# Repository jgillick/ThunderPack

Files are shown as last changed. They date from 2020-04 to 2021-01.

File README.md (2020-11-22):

# ThunderPack

ThunderPack Board

A kick-ass microcontroller board with everything you need in a tiny package that fits in your pocket. Integrated battery & power management system, fast ARM microcontroller, USB bootloader, 4 high-power PWM outputs, 12 GPIOs, satisfying pushbutton switch, and more.

After years of wiring together portable LED controllers that all consisted of a lithium battery, charge controller, shitty slide power switch, and an Arduino nano (or similar), I wanted something better. I always found those versions to be janky and fragile -- not to mention concerned that damaging the pouch cell battery might make it explode in my pocket! This board has everything I need with room to expand.



* [Overview](https://github.com/jgillick/ThunderPack/wiki/)
* [Getting started](https://github.com/jgillick/ThunderPack/wiki/Getting-Started)
* [Pins & functions](https://github.com/jgillick/ThunderPack/wiki/Pinout-Details)
* [Example Programs](./examples)
* [Project log](https://hackaday.io/project/161054-lit-fist)

## Features

ThunderPack Board

* Fast 96Mhz 32-bit ARM microcontroller ([STM32F11xx](https://www.st.com/resource/en/datasheet/stm32f411ce.pdf))
* Integrated high power 500mA lithium battery charger
* 4 high-current PWM outputs (1.4 - 2.3A per channel!) with an LED on each for debugging.
* Additional 12 GPIOs (USART, I2C, SPI, USB)
* 16MB onboard flash
* RGB DotStar LED
* Built-in USB
* Tactile on/off switch
* Momentary button with built-in debounce circuit
* Breadboard friendly
* Supports Arduino & CircuitPython.

On the breadboard

## Board & Pinout

### v1.2 Compact
The newest & smallest Thunderpack, measuring in at a minuscule 4cm x 1.9cm (1.6 x 0.75 inches)! The PWM pins on this model can each drive 1.4A to ground (common cathode).

Compact pinout diagram

[See the full list of pins and details.](https://github.com/jgillick/ThunderPack/wiki/Pinout-Details)

### v1.2 Original
This is the original ThunderPack form factor and has the battery attached right to the circuit board. The PWM pins on this model can each drive 2.3A to ground (common cathode).

Original pinout diagram

[See the full list of pins and details.](https://github.com/jgillick/ThunderPack/wiki/Pinout-Details)

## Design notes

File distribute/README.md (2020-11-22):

# Distribution

This directory contains the default CircuitPython firmware and example code installed onto every ThunderPack that I ship.

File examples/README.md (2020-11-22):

# Example Programs

Thunder Pack can be programed with a variety of languages, libraries and frameworks; each at varying levels of abstraction. CircuitPython and Arduino, for example, have the highest level of abstraction and you don't need to understand much of the inner workings of the chip to get it to do some complex tasks. STM32Cube is at the opposite end of the spectrum where you're working much closer to the chip level. Often this layer of abstraction between the software and hardware is referred to as the Hardware Abstraction Layer (HAL). If you've never programmed microcontrollers before, CircuitPython or Arduino is a great place to start.

I've included a series of simple examples across the following libraries/environments to get you started:

* [CircuitPython](./CircuitPython) - Easily program the board with the Python language. By far the easiest way to start.
* [Arduino](./Arduino) - A common starting place for hobbyists, artists and those new to programming hardware.
* [ChibiOS](./ChibiOS) - A compact [real-time operating system](https://en.wikipedia.org/wiki/Real-time_operating_system) which includes threads & it's own hardware abstraction layer.
* [LibOpenCM3](./libopencm3) - An open source and comprehensive hardware abstraction layer in C and C++.
* [STM32Cube](./STM32Cube) - The default hardware abstraction layer provided by STMicroelectronics and contains quite a few lower level APIs.

Each directory has a README file which explains how to setup, compile and flash the software for that library.

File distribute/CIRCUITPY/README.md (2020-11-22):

ThunderPack 1.2
===============
https://github.com/jgillick/thunderpack/wiki

WARNINGS!
----------------
* ALWAYS use batteries with BUILT-IN protection circuits. _(ThunderPack board does not have any battery protection)_
* Do NOT plug the battery in backward or you could damage the board. (see instructions, below)
* Do NOT exceed the maximum rated power of the battery or components on the board.
* You CANNOT charge the battery through the VIN pin.
* ThunderPack should NOT be used as a chew toy.

ThunderPack was designed for fun and is not intended for life-supporting or business-critical applications.

Maximum Ratings
----------------
* Power Switch maximum ratings: 1A/30V (note 1)
* LED MOSFET maximum ratings:  2.3A/20V
* Onboard Voltage Regulator (AP2210N-3.3TRG1)
  * Output: 3.3V/300mA
  * Input (USB): 2.5-13.2V
* Onboard battery charger (BQ21040): 800mA/4.2V
* Power Pins:
  * 3.3v: 300mA
  * VUSB: USB host max current
  * BATT+: Battery max current
  * VIN: VUSB or BATT+ max (depending on which is powering the board)

Note 1:
You might be wondering how to use the 2.3A MOSFETs if the power switch is only rated at 1A. The MOSFETS are, themselves, switches, so you can connect an LED (or another device) directly from the BATT+ pin to any of the 4 LED pins. The main power switch will control the power to the MCU and that will control switching the MOSFETs. DO NOT connect a high current device directly to VIN, 3.3v, or VUSB.

Getting Started
----------------

### INSERTING THE BATTERY
Look at the diagram on the bottom of the board to see which direction to install the battery. Inserting it backward can damage the board.

The negative end of the battery should be on the USB-side, and the positive side should be on the power switch side of the board.

### RUNNING YOUR FIRST PROGRAM
ThunderPack comes loaded with CircuitPython and a simple test program. Turn the board on with the power switch and you should see the 4 LEDs light up in order. If you do not see this, the battery might be dead. Plug it into a USB charger and charge the battery.

When you plug the board into your computer it should mount as a CircuitPython drive device.
Flashing new firmware
If you want to continue using CircuitPython, updating the firmware is as simple as updating code.py on the USB drive which appears when you plug the board into your computer.

Otherwise, pressing the small tactile button next to the power button while you turn the board on will put it into programming mode. Now you can flash a new firmware program to the board.

### FLASHING FIRMWARE
On most systems, the dfu-util command-line tool (http://dfu-util.sourceforge.net/) will be the easiest way to get new firmware onto the board.

You can confirm that the board is in firmware programming mode by running:
dfu-util --list

To flash a new firmware program (firmware.bin) to the board, run a command like this:
dfu-util -d 0483:df11 -a 0 -s 0x08000000:leave -D ./firmware.bin

### EXAMPLES
There are many examples available for ThunderPack written with Arduino, ChibiOS, libopencm3, CircuitPython, and STM32Cube. You can browse the example library here:
https://github.com/jgillick/ThunderPack/tree/master/examples

Feel free to submit more examples to the project!

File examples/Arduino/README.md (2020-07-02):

# Arduino

Arduino is a great place to start if you're just getting started with microcontrollers. It uses a simplified programming structure with C or C++.

Arduino support is provided on the ThunderPack by the [STM32duino project](https://github.com/stm32duino/Arduino_Core_STM32).

## Software Prerequisites
* [Arduino](https://www.arduino.cc/en/Main/Software)
   * Then install [STM32 Cores 1.8+](https://github.com/stm32duino/wiki/wiki/Getting-Started) in your Arduino application.
* [STM32CubeProgrammer](https://www.st.com/en/development-tools/stm32cubeprog.html)

ℹ️ Mac users: There is a known issue with installing STM32CubeProgrammer on mac. You'll likely need to install it through your terminal application. [more info](https://community.st.com/s/question/0D50X00009XkWmr/install-stm32cubeprogrammer-on-mac-osx-fails-hangs-at-step-6-of-8)

## Setup

Open your Arduino application and make the following selections under the Tools menu:

* Board: Generic STM32L0 series
* Board part number: ThunderPack
* Upload method: STM32CubeProgrammer (DFU)



⚠️ If you do not see those options, make sure that you have [STM32 Cores 1.8+](https://github.com/stm32duino/wiki/wiki/Getting-Started) installed in your Arduino application.

## Programming

1. Open the `ino` file (i.e. Blink.ino) in your Arduino application.
2. Plug your ThunderPack into your computer with a USB cable.
3. Put the ThunderPack in bootloader mode by pressing the tactile button *while* you turn it on. (i.e. press both buttons at the same time)
4. Click Sketch > Upload

Now the program will be compiled and automatically uploaded to your ThunderPack (this might take a couple minutes). If all goes well, and no errors occur, the example program should start automatically.

# Building & Programming

[Instructions](https://github.com/jgillick/ThunderPack/wiki/Getting-Started#arduino) on how to build an example and program it to your ThunderPack with Arduino.

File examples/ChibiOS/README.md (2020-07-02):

# ChibiOS Examples

These examples are written using the [ChibiOS RTOS](http://chibios.org/dokuwiki/doku.php).

## Prerequisites

### Software

* GCC build essentials.
  * Mac: Run `xcode-select --install` in your terminal.
  * Linux: Install [build-essential](https://packages.ubuntu.com/xenial/build-essential)
  * Windows: [make](http://gnuwin32.sourceforge.net/packages/make.htm) or via [cygwin](http://www.cygwin.com/)
* [The ARM gcc toolchain, 7.3.1 or above](https://developer.arm.com/tools-and-software/open-source-software/developer-tools/gnu-toolchain/gnu-rm)
* [dfu-util](http://dfu-util.sourceforge.net/)
* ChibiOS Supporting Files (see below)

### ChibiOS Library

The ChibiOS library is included as a git submodule and needs to be initialized before you can compile any of the examples. (These steps should only need to be run once)

```bash
git submodule init
git submodule update
```

## Compiling

1. Be sure you've installed the prerequisite software and initialized the ChibiOS library first. (see instructions above)
2. Now go into one of the example directories and run `make`.

## Flash the program

Put the board into bootloader (DFU) mode by pressing the user button while turning the board on. Now you can run the following command to flash the program to the board:

```bash
make flash
```

This command is a wrapper for the `dfu-util` command. The full command would be:

```bash
dfu-util -d 0483:df11 -a 0 -s 0x08000000:leave -D build/program.bin
```

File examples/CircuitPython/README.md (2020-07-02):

# CircuitPython / MicroPython
[CircuitPython](https://circuitpython.org/) enables Python code to run on the Thunderpack and is one of the easiest ways to get started with Microcontrollers. But first, you'll need to load the CircuitPython framework onto the board.

You can download the CircuitPython runtime binary for Thunderpack from here:
https://circuitpython.org/board/thunderpack/

Then use the following setup instructions to learn how to get this binary running on Thunderpack.

## Initial Setup
First make sure you have either [dfu-util](http://dfu-util.sourceforge.net/) or [STM32CubeProg](https://www.st.com/en/development-tools/stm32cubeprog.html) installed on your computer.

### Enter DFU bootloader mode
Put the ThunderPack in bootloader mode by pressing the tactile button *while* you turn it on. (i.e. press both buttons at the same time)

### Updating the board

#### DFU-UTIL
If you're using dfu-util, run this command (be sure the path to the `.bin` file is correct):

```bash
dfu-util -d 0483:df11 -a 0 -s 0x08000000:leave -D ./adafruit-circuitpython-thunderpack-en_US-5.2.0.bin
```

#### STM32CubeProg
If your're using STM32Cube, open the application and use it to program [the binary](https://circuitpython.org/board/thunderpack/) to the board.

You can see comprehensive instructions with screenshots [here](https://learn.adafruit.com/adafruit-stm32f405-feather-express/dfu-bootloader-details).

## Using CircuitPython
If everything worked right, when you restart your board it will mount to your computer as a disk drive called "CIRCUITPY". This can take up to 30 seconds on the first boot.

To try an example, simply add the `code.py`file (and the `lib` directoy, if present) to the mounted drive and in few seconds the board will update to run it.

Learn more at [CircuitPython](https://circuitpython.org/)

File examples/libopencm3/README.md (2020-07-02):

# LibOpenCM3

Examples written using the [libopencm3](https://github.com/libopencm3/libopencm3) library.

## Prerequisites

### Software

* GCC build essentials.
  * Mac: Run `xcode-select --install` in your terminal.
  * Linux: Install [build-essential](https://packages.ubuntu.com/xenial/build-essential)
  * Windows: [make](http://gnuwin32.sourceforge.net/packages/make.htm) or via [cygwin](http://www.cygwin.com/)
* [The ARM gcc toolchain, 7.3.1 or above](https://developer.arm.com/tools-and-software/open-source-software/developer-tools/gnu-toolchain/gnu-rm)
* [dfu-util](http://dfu-util.sourceforge.net/)

### LibOpenCM3 Library

The LibOpenCM3 library is included as a git submodule and needs to be initialized and built before you can compile any of the examples. (These steps should only need to be run once)

```bash
cd ThunderPack/examples/libopencm3
git submodule init
git submodule update
make
```

## Compile

1. Be sure you've installed the prerequisite software and initialized the LibOpenCM3 library first. (see instructions above)
2. Now go into one of the example directories and run `make`.

**For Example:**

```bash
cd examples/libopencm3

make

cd ./Blink

make
```

## Flash the program

Put the board into bootloader (DFU) mode by pressing the user button while turning the board on. Now you can run the following command to flash the program to the board:

```bash
make flash
```

This command is a wrapper for the `dfu-util` command. The full command would be:

```bash
dfu-util -d 0483:df11 -a 0 -s 0x08000000:leave -D build/program.bin
```

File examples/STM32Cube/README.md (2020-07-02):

# STM32Cube

Examples written using [STM32Cube](https://www.st.com/content/st_com/en/products/embedded-software/mcu-mpu-embedded-software/stm32-embedded-software/stm32cube-mcu-mpu-packages/stm32cubef4.html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), which are the official hardware extraction layer (HAL) and libraries from STMicroelectronics.

The base configurations (clock, gpio, etc) are generated using the [STM32CubeMX](https://www.st.com/en/development-tools/stm32cubemx.html) code generator.

## Prerequisites

### Software

* GCC build essentials.
  * Mac: Run `xcode-select --install` in your terminal.
  * Linux: Install [build-essential](https://packages.ubuntu.com/xenial/build-essential)
  * Windows: [make](http://gnuwin32.sourceforge.net/packages/make.htm) or via [cygwin](http://www.cygwin.com/)
* [The ARM gcc toolchain, 7.3.1 or above](https://developer.arm.com/tools-and-software/open-source-software/developer-tools/gnu-toolchain/gnu-rm)
* [dfu-util](http://dfu-util.sourceforge.net/)

## Compile

To compile each example, you should only need to run `make` from within the example directory.

```bash
cd ./Blink

make
```

## Flash the program

Put the board into bootloader (DFU) mode by pressing the user button while turning the board on. Now you can run the following command to flash the program to the board:

```bash
make flash
```

This command is a wrapper for the `dfu-util` command. The full command would be:

```bash
dfu-util -d 0483:df11 -a 0 -s 0x08000000:leave -D build/program.bin
```

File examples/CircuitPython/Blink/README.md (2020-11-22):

# Blink

The ubiquitous "Hello World" of hardware examples. This simply blinks the LED 1 (PA0). Pressing the button will blink the LED faster.

## Compiling/Flashing
See the instructions [here](../README.md)

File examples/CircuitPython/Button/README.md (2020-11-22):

# Button Example

Turns on LED 1 when the button is pressed.

## Compiling/Flashing
See the instructions [here](../README.md)

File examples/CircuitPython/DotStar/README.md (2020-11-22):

# DotStar
This CircuitPython example controls the onboard RGB dotstar LED and cycles it's color around the color wheel. You can easily modify this program to control external DotStar LEDs by changing the pins that are use.

## Compiling/Flashing
See the instructions [here](../README.md)

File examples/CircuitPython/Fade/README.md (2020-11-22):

# Fade

Uses PWM to fade LED 1 on and off.

## Compiling/Flashing
See the instructions [here](../README.md)

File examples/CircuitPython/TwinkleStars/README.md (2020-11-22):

# CircuitPython Twinkle Stars

This is a CircuitPython program which uses a few outputs and some fairy string lights to produce a cool twinkling stars effect. Some LEDs are set to twinkle on and off, while others will have a longer fade up and down.

Twinkling

## How Fairy String LEDs Help

Often fairy string lights wire up their LEDs parallel with alternating polarities. This way, when wire 1 is positive and wire 2 is negative, every second LED is illuminated. When the polarity of the wires reverses (wire 1: negative, wire 2: positive) the other LEDs turn on.

This clever technique let's fairy string lights do a variety of animations with fewer wires by swapping the polarities at different rates.

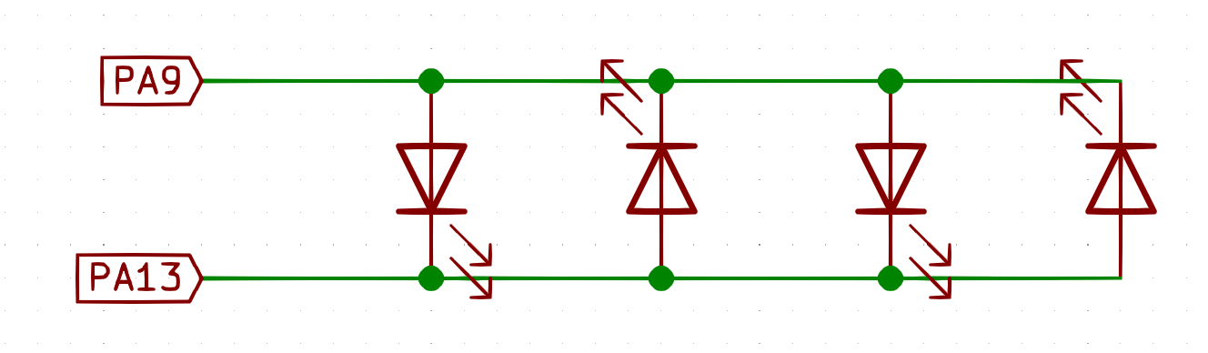
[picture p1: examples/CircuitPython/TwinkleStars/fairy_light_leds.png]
Fairy String LEDs Schematic


## Setup

There will be two groups of LEDs: twinkling and fading. The fading LEDs will just fade on and off. The twinkling LEDs will swap the power polarity to a string of LEDs with randomized timing.

### Fade LEDs

Connect LEDs to the first three PWM outputs, ensuring you have the polarity correct. The fading LEDS will not use the swapped polarity feature.

### Twinkle LEDs

Cut a string of fairy lights into sections. Test the current draw on each twinkle section and make sure it does not draw more than 20mA. If it does, you might need to add a mosfet to protect the microcontroller. Add an inline resistor as necessary.

Take each section and connect one of the wires to one GPIO and the other one to another GPIO. I used: `PA9`, `PA13`, `PA14`, and `PB5`.

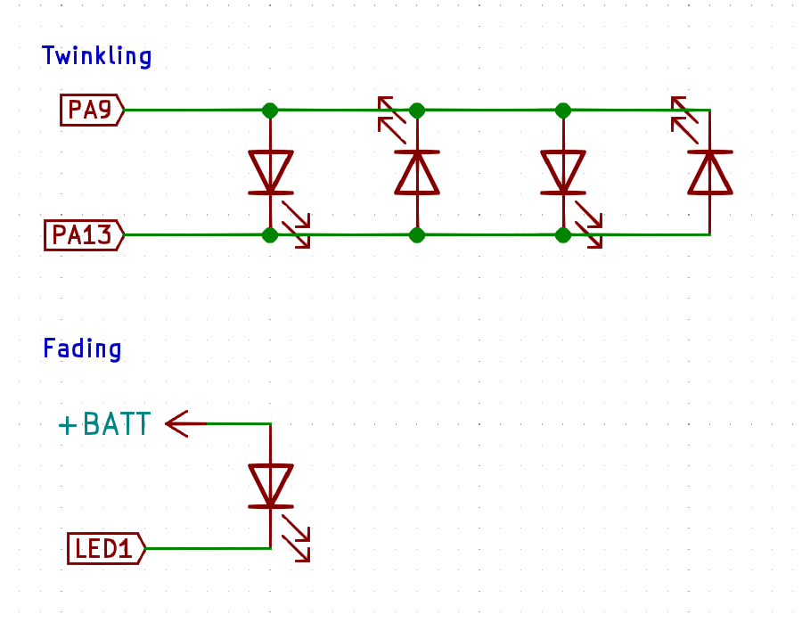
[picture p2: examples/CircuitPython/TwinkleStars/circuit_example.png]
Example Circuit


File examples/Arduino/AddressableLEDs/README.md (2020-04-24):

# Addressable LEDs (WS2812B)
Controls a string of addressable WS2812B LEDs (like [Neopixels](https://www.adafruit.com/category/168)). This example controls 16 LEDs, which is configurable by the `LED_COUNT` value in `src/main.c`.

## Connections

From the LED strip, connect:

* Data -> `PA7`
* Power -> `Vin` or `Batt+`
* Ground -> `GND`

## WS2812B API Library
Read about how to use the provided WS2812B APIs in the [WS2812b.h](./WS2812b.h) file.

### Example
```cpp
// Initialize LED strip
#define DATA_PIN  PA7
#define LED_COUNT 16
WS2812b led_strip = WS2812b(DATA_PIN, LED_COUNT);

// Set brightness on 3 neopixels
led_strip.set(0, 0xFF, 0x00, 0x00); // LED 1 red
led_strip.set(1, 0x00, 0xFF, 0x00); // LED 2 green
led_strip.set(2, 0x00, 0x00, 0xFF); // LED 3 blue

// Send data (if you forget this line, nothing will be sent to your LED strip)
led_strip.show();
```

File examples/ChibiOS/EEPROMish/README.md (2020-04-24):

# EEPROMish - Non-Volatile Memory

A simple example to demonstrate storing a value in non-volatile memory.

When the program starts, one of the LEDs will light up. Pressing the button will light the next LED, and so on and so forth. When you turn the board off and on again, the previously lit LED will be remembered and be the starting LED.

## STM32Cube with Chibios

ChibiOS doesn't have any functions to interface with on-board flash memory for the STM32F411 chip, so this example shows how to include the [STM32Cube library](https://www.st.com/content/st_com/en/products/embedded-software/mcu-mpu-embedded-software/stm32-embedded-software/stm32cube-mcu-mpu-packages/stm32cubel0.html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) into a ChibiOS project and use the flash functions in it.

In this case we're using the driver files located in the [STM32Cube examples](../../STM32Cube/) directory. You can just as easily use files generated by the STM32CubeMX tool.

## How it works
The STM32F411 chip does not have built-in [EEPROM memory](https://en.wikipedia.org/wiki/EEPROM). However, it allows you to write to sectors of it's internal flash memory in a similar way to EEPROM.

Each time the user presses the button to change the lit LED, the code saves this value to a byte address in the flash memory.

Inside the chip, the flash memory is devided into 11 sectors. In our case we reserved sector 1 for non-volatile memory. Before writing to a sector, the entire sector needs to be erased. To prevent the firmware from being loaded into this section, we updated the linker file ([STM32F411CEUx_FLASH_NVM.ld](./STM32F411CEUx_FLASH_NVM.ld)) to reserve sector 1 for data.

### What's the catch?
There are a few:

* It uses the same memory as the firmware, so it _might_ be erased when the firmware is updated.
* Writing to flash is slower than EEPROM.
* Flash memory might start corrupting after 10k write cycls. EEPROM can handle up to 1 million write cycles.

### Additional information
This example is pretty basic, but if you plan to write to this often, you might want to read about proper [EEPROM emulation techniques](https://www.st.com/resource/en/application_note/dm00036065-eeprom-emulation-in-stm32f40xstm32f41x-microcontrollers-stmicroelectronics.pdf).

## Compiling/Flashing
See the instructions [here](../README.md)

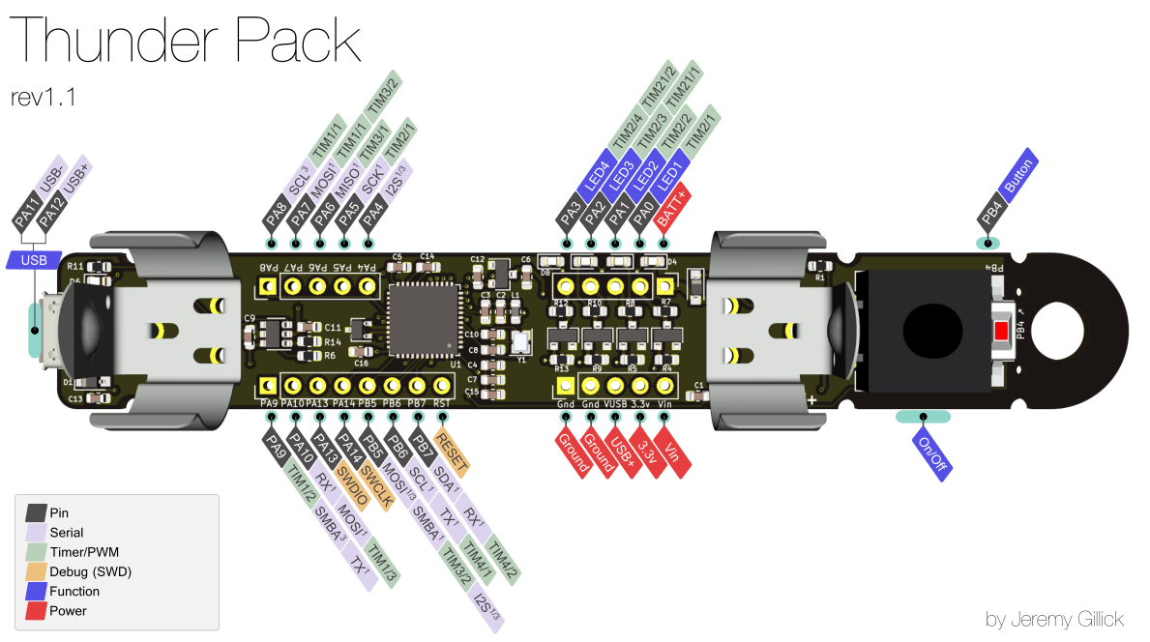
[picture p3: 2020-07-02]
images/pinout.png

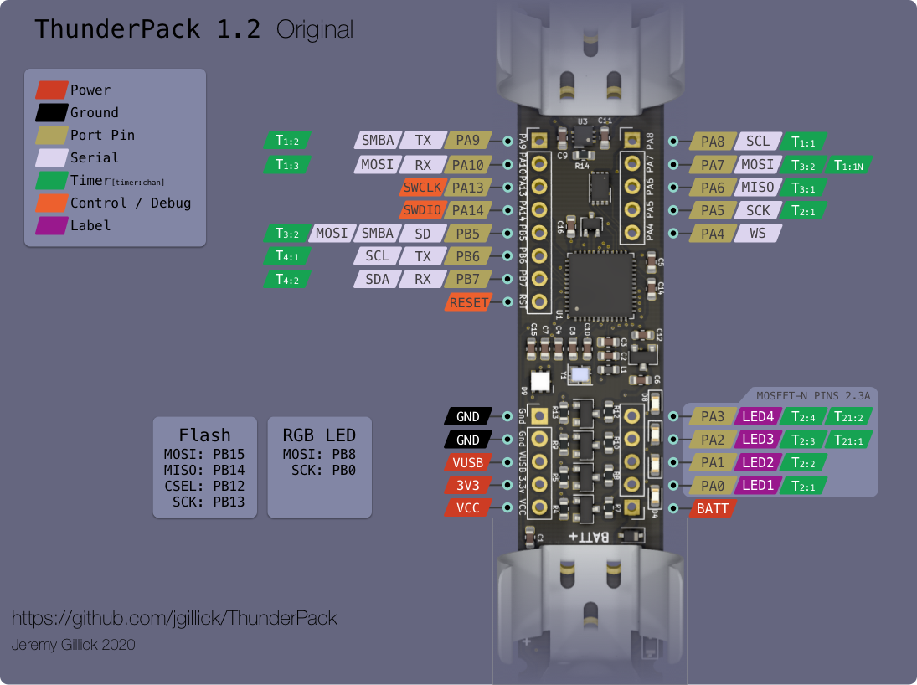
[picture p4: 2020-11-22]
hardware/Original/pinout/pinout_small.png

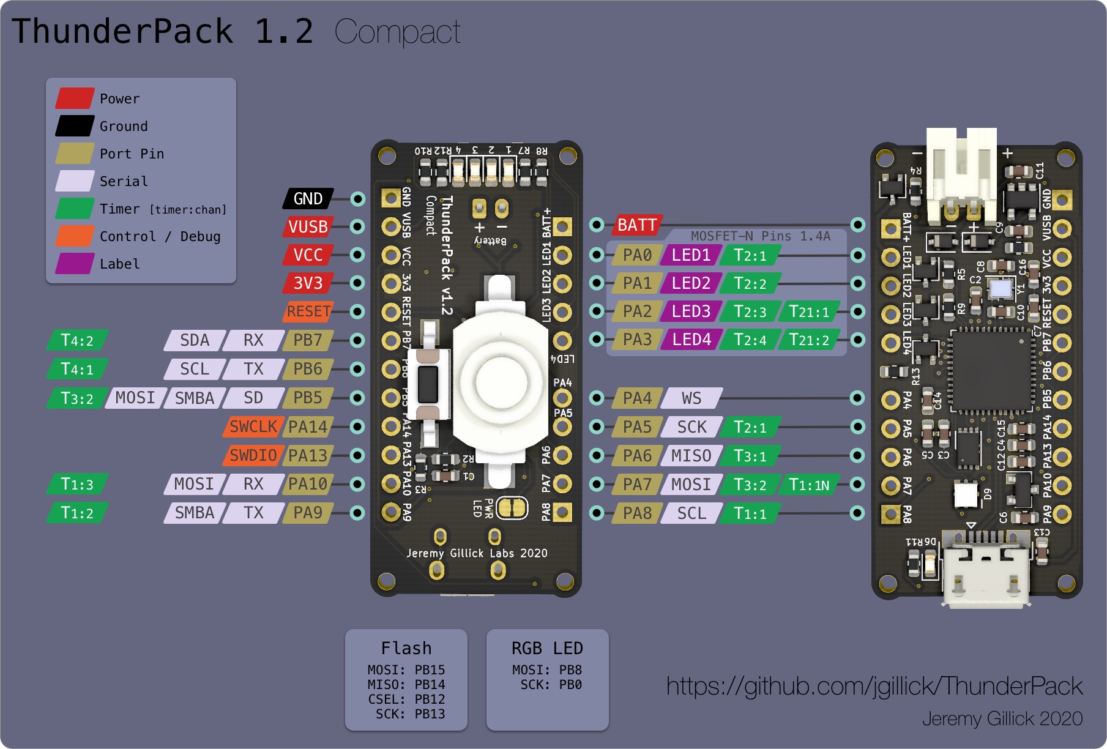
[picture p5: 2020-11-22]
hardware/Compact/pinout/pinout.jpg

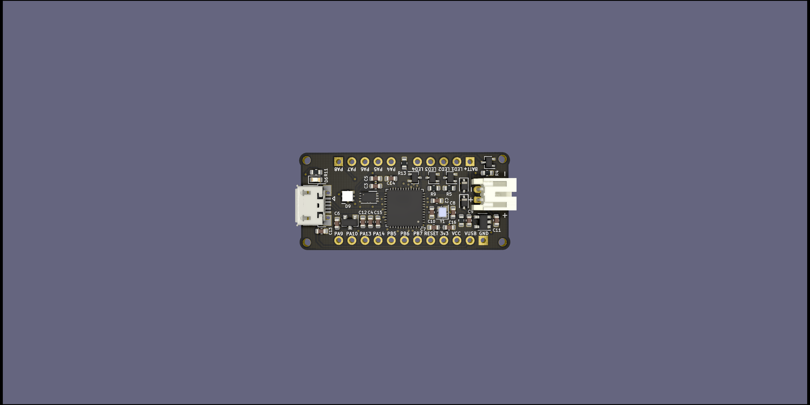
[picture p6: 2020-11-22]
hardware/Compact/Renderings/Back.png

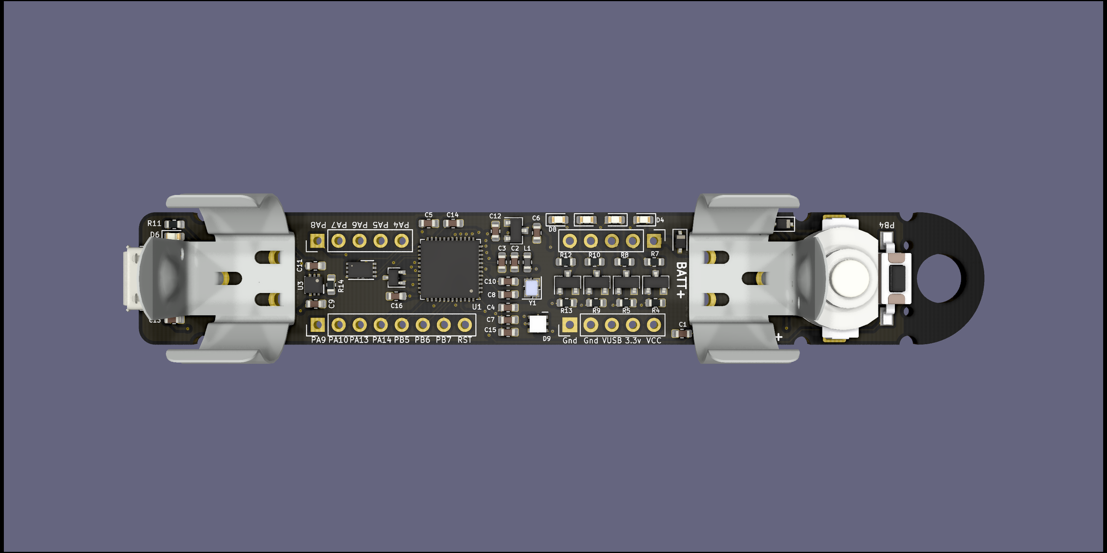
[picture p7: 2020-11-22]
hardware/Original/render.png

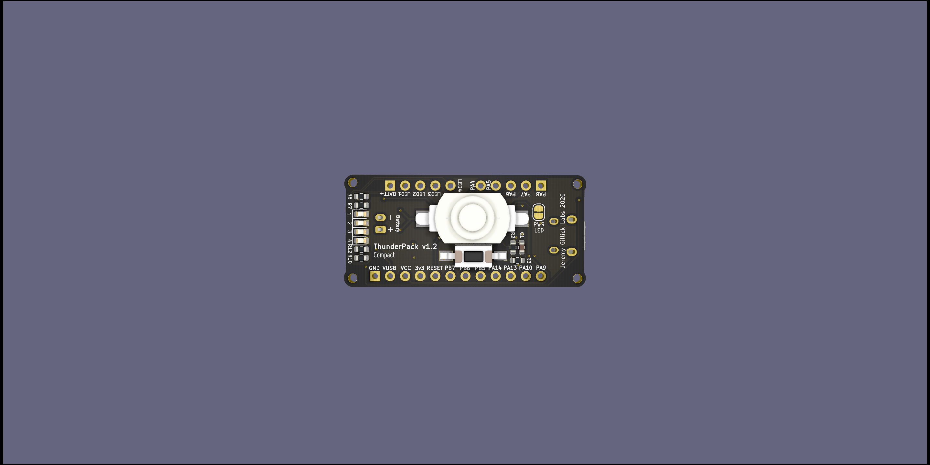
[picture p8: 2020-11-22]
hardware/Compact/Renderings/Front.png

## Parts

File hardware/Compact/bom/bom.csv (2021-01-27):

Id | Designator | Manufacturer | Quantity | *Mfg Part # | Value | Package | Description / Value | Type | Notes
1 | U4 | ON Semiconductor | 1 | ESD7002WTT1G |  | SOT-323_SC-70 | TVS DIODE 5V SC70-3 | SMD
2 | D9 | SparkFun Electronics | 1 | APA102-2020 |  | LED-APA102-2020 | ADDRESS LED STRIP SER RGB 10PK | SMD
3 | J2 | TE Connectivity | 1 | 440055-2 |  | JST_PH_S2B-PH-K_1x02_P2.00mm_Horizontal | Connector Header Through Hole, Right Angle 2 position 0.079" (2.00mm) | thru-hole
4 | R12,R10,R8,R7,R3,R11,R1 |  | 7 |  | 330 | 0603 | RES SMD 330 OHM 0.5% 1/5W 0603 | SMD
5 | D6 | Würth Elektronik | 1 | 150060SS75000 |  | 0603 | LED RED CLEAR 0603 SMD | SMD
6 | D8,D7,D5,D4 | Würth Elektronik | 4 | 150060VS75000 |  | 0603 | LED GREEN CLEAR 0603 SMD | SMD
7 | D1,D2 | Micro Commercial Co | 2 | SMD22WS-TP |  | SOD-323 | 2A,20V,SCHOTTKY,SOD-323 PACKAGE | SMD
8 | SW1 | TE Connectivity | 1 | FSMSM |  |  | SWITCH TACTILE SPST-NO 0.05A 24V | SMD
9 | U5 | GigaDevice Semiconductor | 1 | GD25Q16CEIGR |  | 8-XFDFN | FLASH - NOR Memory IC 16Mb (2M x 8) SPI - Quad I/O 120MHz 8-USON (2x3) | SMD
10 | U1 | STMicroelectronics | 1 | STM32F411CEU6 |  | 48-UFQFN | IC MCU 32BIT 512KB FLSH 48UFQFPN | SMD
11 | Q2,Q4,Q3,Q1 | Infineon Technologies | 4 | BSS816NWH6327XTSA1 |  | SOT-323 | MOSFET N-CH 20V 1.4A SOT323-3 | SMD
12 | R13,R9,R5,R4,R2 |  | 5 |  | 20k | 0603 | RES SMD 20K OHM 0.5% 1/10W 0603 | SMD
13 | C1,C4,C16,C5,C3 |  | 5 |  | 100nF | 0603 | CAP CER 0.1UF 50V X7R 0603 | SMD
14 | U3 | Microchip Technology | 1 | MCP73831T-2ACI/OT |  | SOT-23-5 | IC BATT CNTL LI-ION 1CEL SOT23-5 | SMD
15 | R6 |  | 1 |  | 2k | 0603 | RES 2K OHM 1% 1/10W 0603 | SMD
16 | C11,C9,C14,C7 |  | 4 |  | 4.7uF | 0603 | CAP CER 4.7UF 16V X5R 0603 | SMD
17 | D3 | Würth Elektronik | 1 | 150060BS55040 |  | 0603 | LED BLUE DIFFUSED 0603 SMD | SMD
18 | C12 |  | 1 |  | 2.2uF | 0603 | CAP CER 2.2UF 16V X5R 0603 | SMD
19 | Y1 | XRCGB24M000F0L00R0 | 1 | 24Mhz |  | 4-SMD | CRYSTAL 24.0000MHZ 6PF SMD | SMD
20 | U2 | Diodes Incorporated | 1 | AP2210N-3.3TRG1 |  | SOT-23-3 | IC REG LINEAR 3.3V 300MA SOT23-3 | SMD
21 | J4 | Amphenol ICC (FCI) | 1 | 10103594-0001LF |  |  | CONN RCPT USB2.0 MICRO B SMD R/A | SMD
22 | C13,C6,C2 |  | 3 |  | 1uF | 0603 | CAP CER 1UF 25V X5R 0603 | SMD
23 | C10,C8 |  | 2 |  | 6pF | 0603 | CAP CER 6PF 50V C0G/NP0 0603 | SMD

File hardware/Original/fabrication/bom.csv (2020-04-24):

Id | RefDefs | Package | Qty | Value | part number/description
1 | D2,D1 | D_SOD-323 | 2 | 20V2A | SMD22WS-TP
2 | Y1 | 4-SMD | 1 |  | XRCGB24M000F0L00R0
3 | U1 | 48-UFQFPN | 1 |  | STM32F411CEU6
4 | R6 | 603 | 1 | 680R
5 | C16,C15,C4,C1,C3,C5 | 603 | 6 | 100nF | CC0603KRX7R9BB104
6 | C14,C7 | 603 | 2 | 4.7uF | CC0603KRX5R5BB475
7 | U3 | SOT-23-6 | 1 |  | BQ21040
8 | D6 | 603 | 1 |  | 150060BS55040
9 | D8,D7,D5,D4 | 603 | 4 |  | 150060VS75000
10 | R14 | 603 | 1 | 10k
11 | R11,R3 | 603 | 2 | 330R
12 | C11,C12,C9,C13,C6,C2 | 603 | 6 | 1uF | CC0603KRX7R7BB105
13 | U4 | SOT-323_SC-70 | 1 |  | ESD7002WTT1G
14 | U2 | SOT-23 | 1 |  | AP2210N-3.3TRG1
15 | J4 | USB Micro | 1 |  | Amphenol 10103594-0001LF
16 | SW2 |  | 1 |  | GPTS203211B
17 | SW1 |  | 1 |  | TE Connectivity FSMSM
18 | L1 | 603 | 1 |  | BLM18TG601TN1D
19 | R1,R7,R8,R10,R12 | 603 | 5 | 270R
20 | R2,R4,R5,R9,R13 | 603 | 5 | 20k
21 | C8,C10 | 603 | 2 | 6pF | CL10C060CB8NNNC
22 | Q1,Q3,Q4,Q2 | SOT-23 | 4 |  | BSS806N
23 | D3 | 603 | 1 |  | 150060SS75000

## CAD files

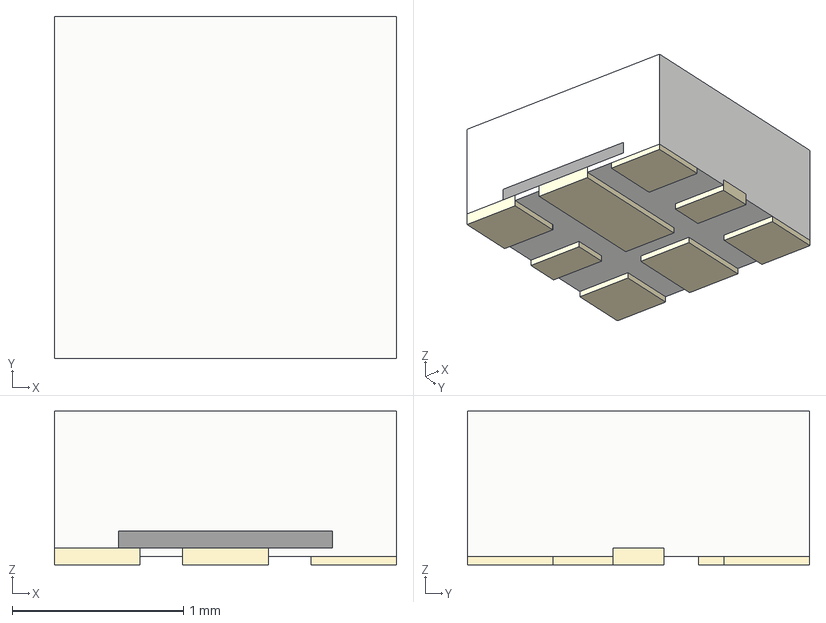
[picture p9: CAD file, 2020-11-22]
hardware/Compact/APA102-2020.step
2.00 x 2.00 x 0.9 mm
IC

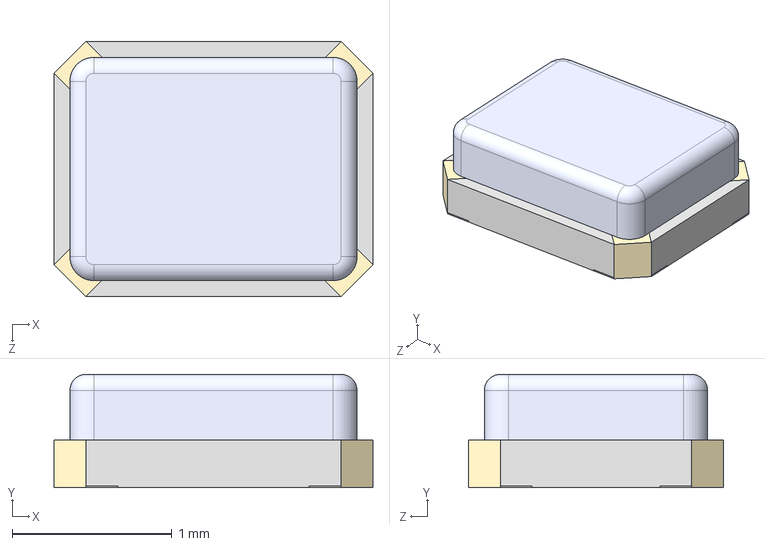
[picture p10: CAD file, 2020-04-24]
hardware/Original/XRCGB27M120F3A00R0--3DModel-STEP-56544.STEP
2.00 x 0.71 x 1.60 mm

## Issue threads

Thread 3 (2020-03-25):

Plans for selling these?

jamesmunns, 2020-03-25:
Hey there! This looks exactly like something I was planning to make (for a WS2812 dog collar), and I was wondering if you planned on selling these anywhere like Tindie.

For my use, either the STM32L0 or the new STM32F4 parts should work (I'll write the firmware in Rust instead of CircuitPython), so either revision works for me!

Thanks for sharing an awesome project!

jgillick, 2020-03-27:
Yeah, I was considering doing a small run and trying to sell a few on Tindie. I'm finishing up some of the remaining testing/documenting and then will put an order in and let you know.

If you plan to write some firmware in Rust, I'd love to get a boilerplate I could include in the examples sections. I've been planning to try learning Rust soon.

jamesmunns, 2020-03-27:
Sure! I recently did something similar for the [OtterPill](https://github.com/jamesmunns/OtterPill-rs/), the stm32 family is super well supported in Rust, so happy to contribute some boilerplate/examples.

I live in Germany, but happy to pay for international shipping as well, though it would be good to buy a couple boards at once :) probably count me in for 3-5, depending on the cost of each. I have a bunch of 18650s laying around, so i’d be interested in that version.

jgillick, 2020-03-28:
OtterPill is also a board I've been wanting to play with. Really nice design and I'm impressed with the cost the creator was able to get it down to.

Thanks for letting me know how many you're interested in. I'll let you know the price when I get the order setup with PCBWay.

mattpackwood, 2020-04-29:
Do you have a Tindie ID?

jgillick, 2020-05-02:
Not yet, but I'll be setting that up very soon. I should be getting the first batch of boards from the manufacturer sometime around middle of this month.

mattpackwood, 2020-05-02:
Hopefully, you can let me know when that happens!

mattytrentini, 2020-05-20:
Wouldn't mind getting my hands on one of these to create a MicroPython board definition. There are already existing [STM32F11 boards](https://github.com/micropython/micropython/tree/master/ports/stm32/boards) so it should be trivial...so yes, please let us know when you put sell these on Tindie!

jgillick, 2020-05-20:
PCBWay is running a little behind as they had a problem with sourcing one of the components. I'll let you know the updated timeline as soon as they get that to me.

@mattytrentini Yeah, creating a MicroPython board definition for this should be pretty straight forward!

jgillick, 2020-06-07:
Good news! I just received the small production run from PCBWay and they're beautiful. I'm still waiting on the shipment of batteries, but once I get them I'll be listing these for sale on my Tindie shop. (Shipping amid COVID is making things take much longer to receive than usual).

Tindie Shop: https://www.tindie.com/stores/jeremy/

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

jgillick, 2020-06-25:
It took MUCH longer to get this setup than expected, but I have the product listed on Tindie:
https://www.tindie.com/products/jeremy/thunderpack-18650/

Let me know if you need any help. This is my first time setting up a shop on Tindie.

Closed 2020-11-20.

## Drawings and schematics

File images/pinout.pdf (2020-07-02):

# Thunder Pack

# rev1.1

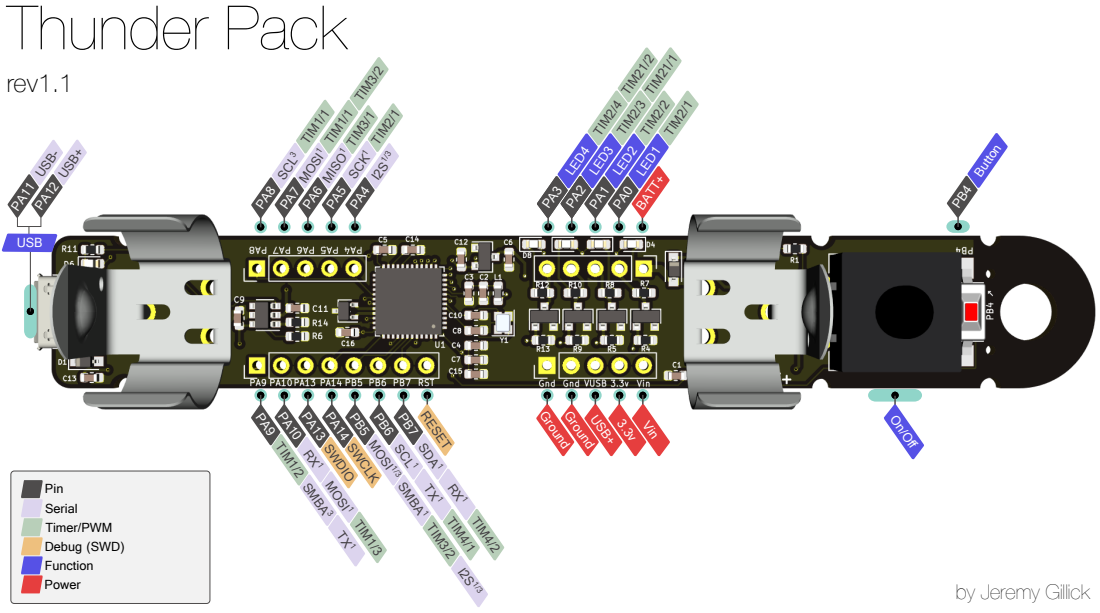
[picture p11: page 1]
MOSI1 TIM1/1; TIM3/2; TIM1/1; SCK1 TIM2/1; MISO1 PA6; TIM3/1; SCL3; TIM2/4; LED4; TIM21/2; TIM2/3; LED3; TIM21/1; TIM2/2; LED2; TIM2/1; LED1; BATT+; SMBA3; MOSI1; SWDIO; SWCLK; MOSI1/3; SMBA1 PB5; TIM1/2; TIM1/3; TIM4/1; TIM4/2; SCL1 TX1; SDA1 RX1; RESET; Ground USB+ 3.3v Vin; On/Off; Button; USB; USB-; USB+; Ground; Pin Serial Timer/PWM Debug (SWD) Function Power

by Jeremy Gillick

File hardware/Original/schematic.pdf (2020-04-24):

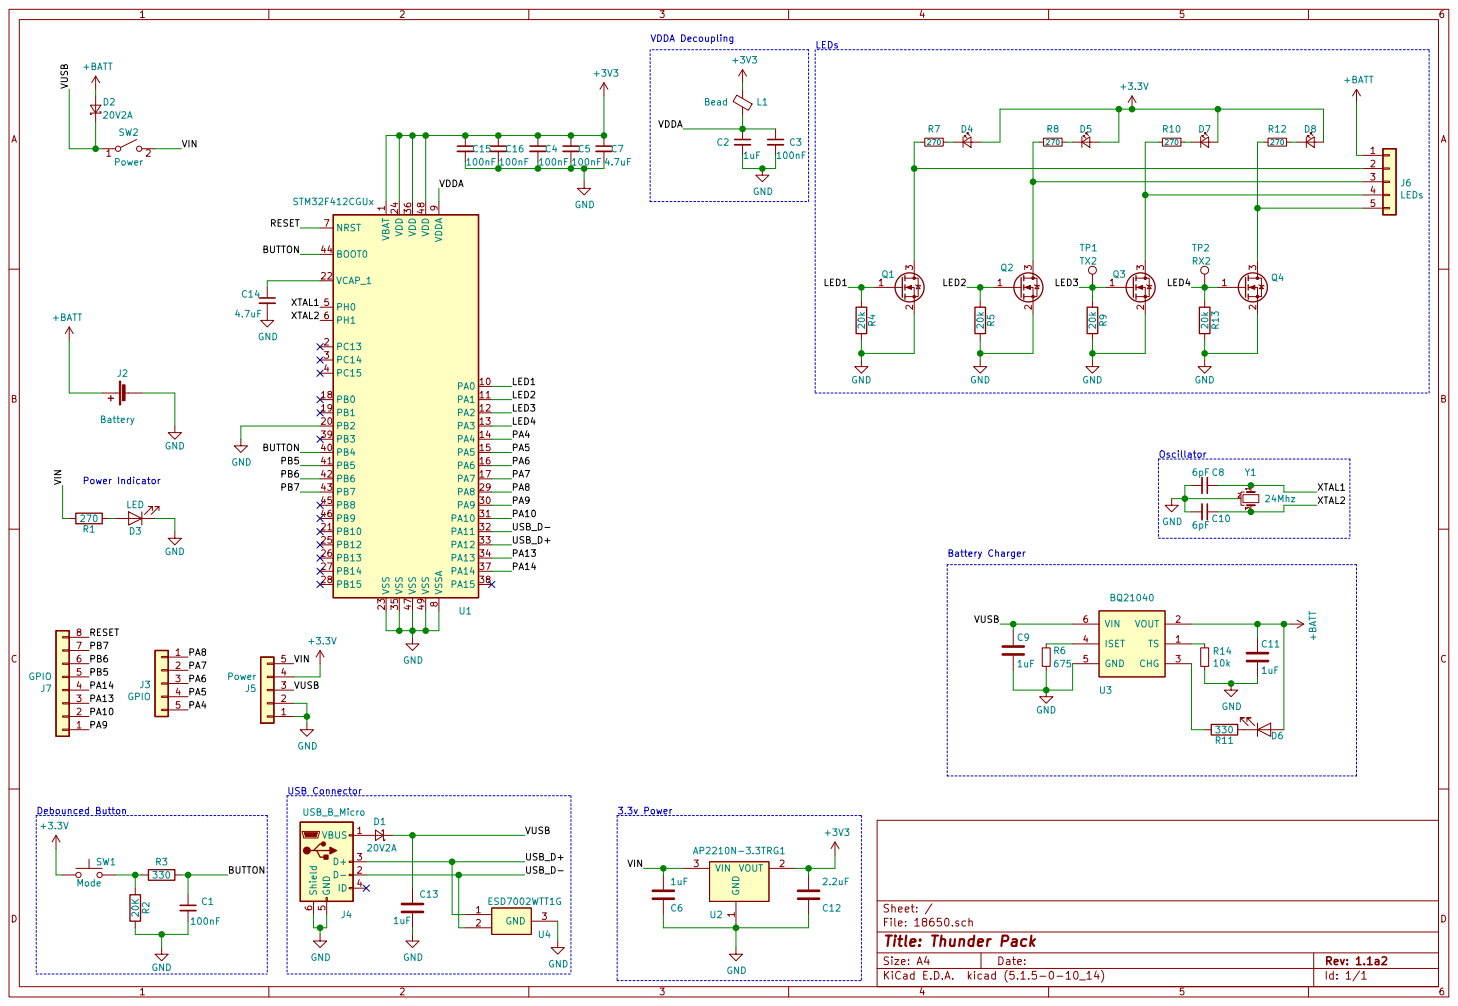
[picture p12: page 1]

1 VCAP_1 22 VDD 24 VDD 36 VDD 48 VDDA

9 VSS 23 VSS 35 VSS 47 VSS 49 VSSA

Id: 1/1 Title: Thunder Pack

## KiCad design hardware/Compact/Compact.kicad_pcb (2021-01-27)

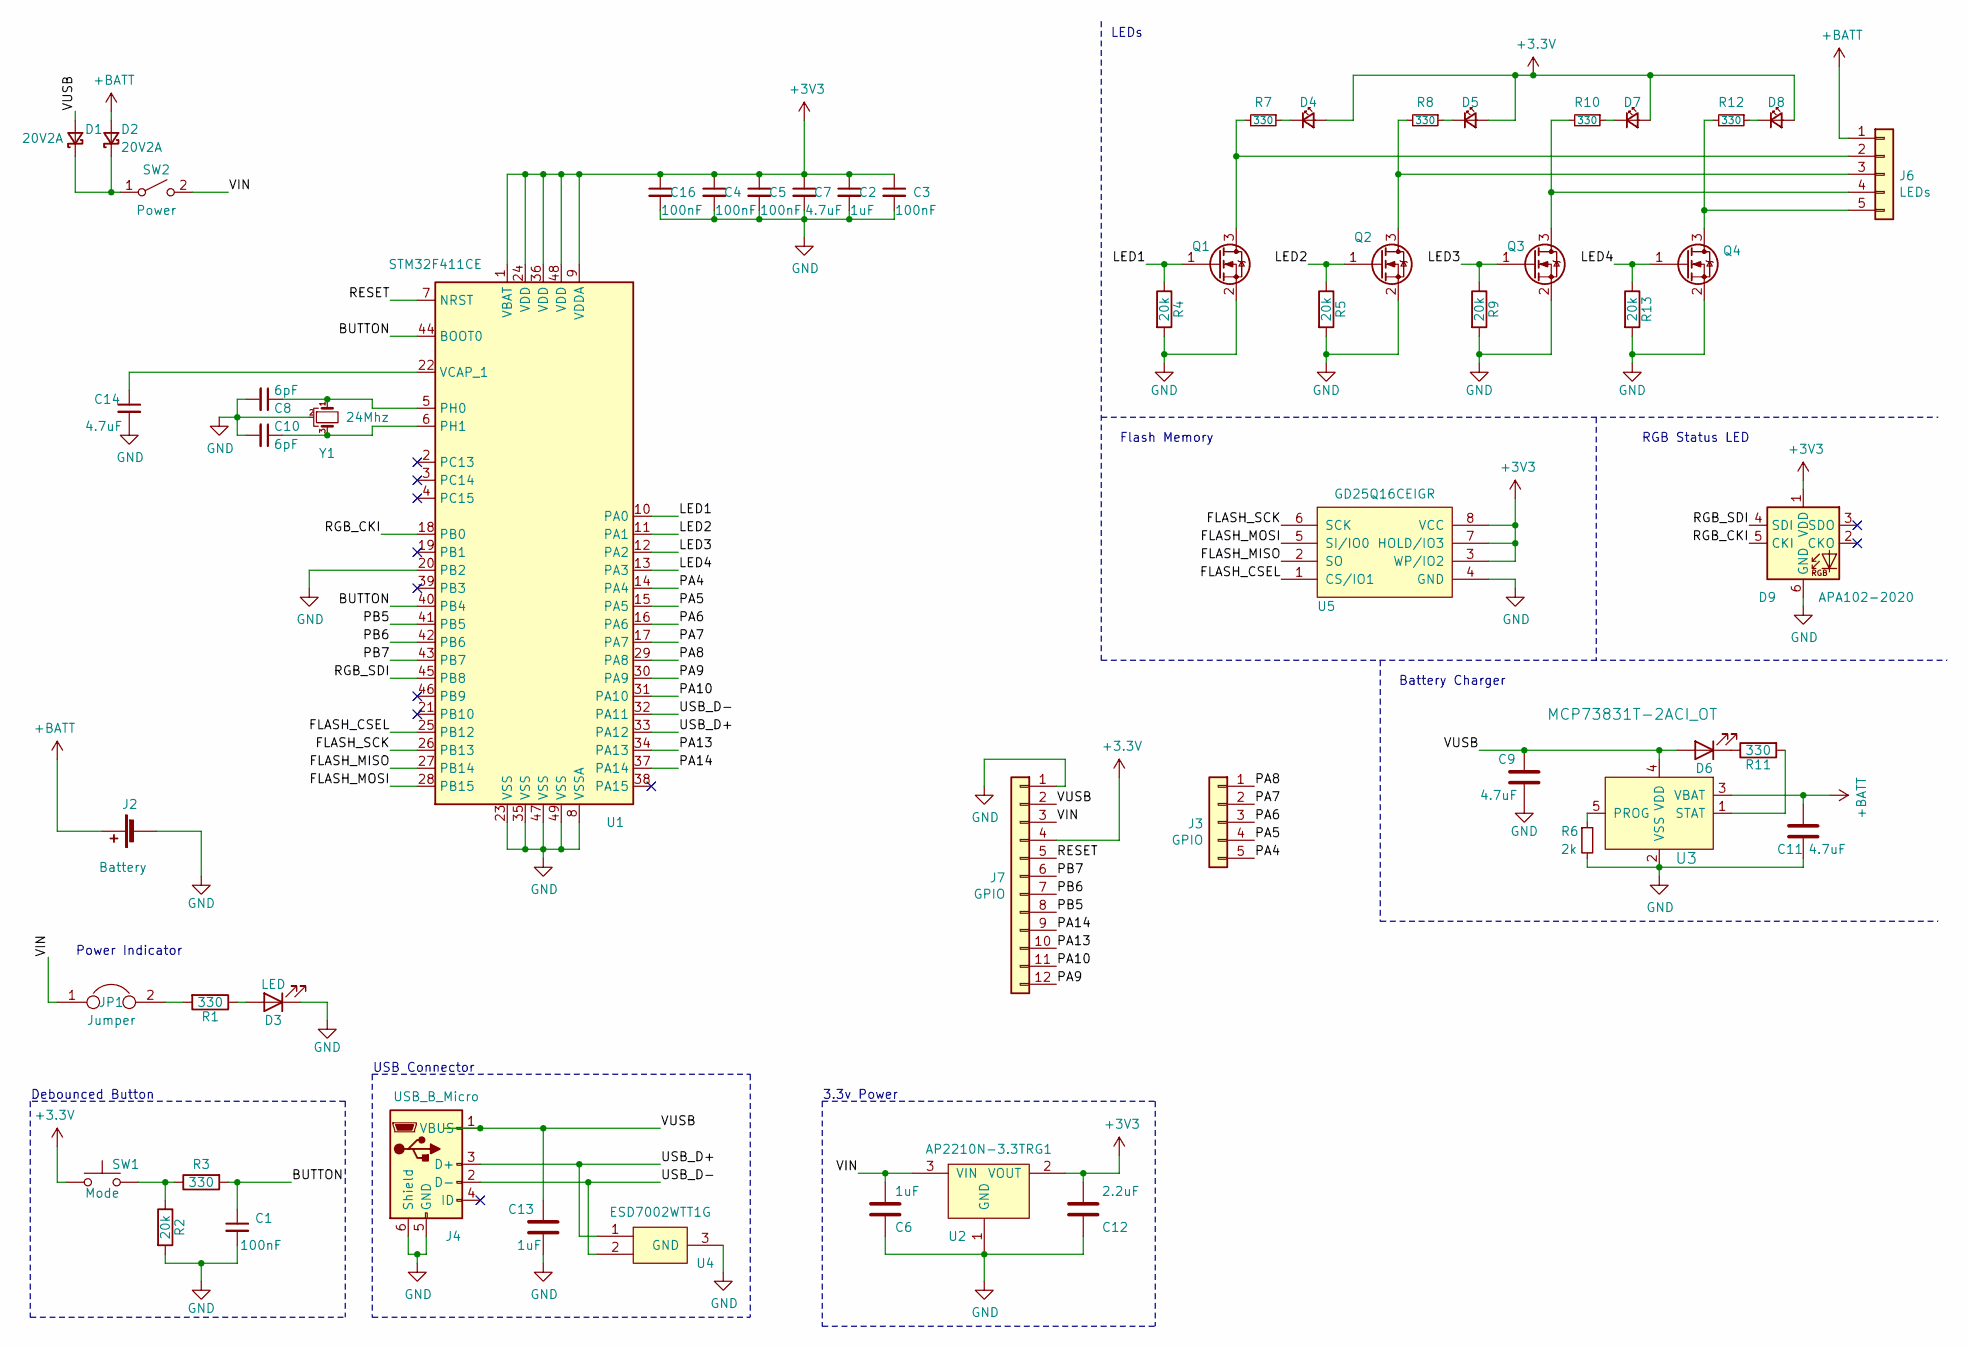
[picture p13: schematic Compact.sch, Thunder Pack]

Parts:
C1: 100nF; C_0603_1608Metric; MPN MF-CAP-0603-0.1uF
C2: 1uF; C_0603_1608Metric; MPN MF-CAP-0603-1uF
C3: 100nF; C_0603_1608Metric; MPN Yageo
C4, C5, C16: 100nF; C_0603_1608Metric; MPN 06035C104K4T2A
C6, C13: 1uF; C_0603_1608Metric
C7, C14: 4.7uF; C_0603_1608Metric; MPN CL10A475KO8NNNC‎
C8, C10: 6pF; C_0603_1608Metric; MPN CL10C060CB8NNNC; Digikey 1276-2133-1-ND
C9, C11: 4.7uF; C_0603_1608Metric
C12: 2.2uF; C_0603_1608Metric; MPN CL10A225KO8NNNC
D1, D2: 20V2A; D_SOD-323; MPN SMD22WS-TP
D3: LED; LED_0603_1608Metric_Castellated; MPN 150060BS55040
D4, D5, D7, D8: LED; LED_0603_1608Metric; MPN 150060VS75000
D6: LED; LED_0603_1608Metric; MPN 150060SS75000
D9: APA102-2020; LED-APA102-2020
J2: Battery; JST_PH_S2B-PH-K_1x02_P2.00mm_Horizontal; MPN Keystone 54; Digikey 36-54-ND
J3: GPIO; PinHeader_1x05_P2.54mm_Vertical
J4: USB_B_Micro; USB_Micro-B_Amphenol_10103594-0001LF_Horizontal; MPN 10103594-0001LF
J6: LEDs; PinHeader_1x05_P2.54mm_Vertical
J7: GPIO; PinHeader_1x12_P2.54mm_Vertical
JP1: Jumper; SolderJumper-2_P1.3mm_Bridged_RoundedPad1.0x1.5mm
Q1, Q2, Q3, Q4: BSS806N; SOT-323_SC-70; MPN BSS816NWH6327XTSA1
R1: 330; R_0603_1608Metric
R2, R4, R5, R9, R13: 20k; R_0603_1608Metric; MPN CR0603-FX-2002ELF
R3: 330; R_0603_1608Metric; MPN MF-RES-0603-330
R6: 2k; R_0603_1608Metric; MPN RMCF0603FT2K00
R7, R8, R10, R12: 330; R_0603_1608Metric; MPN CRCW0603270RJNEA
R11: 330; R_0603_1608Metric; MPN ERJ-PA3F4300V
SW1: Mode; SW_SPST_FSMSM; MPN 1437566-3; Digikey 450-1140-ND
SW2: Power; SW_KAN-15_SMD; MPN KAN15
U1: STM32F411CE; QFN-48-1EP_7x7mm_P0.5mm_EP5.6x5.6mm; MPN STM32F411CE
U2: AP2210N-3.3TRG1; SOT-23; MPN AP2210N-3.3TRG1
U3: MCP73831T-2ACI_OT; SOT-23-5; MPN MCP73831T-2ACI/OT; Digi-Key_PN MCP73831T-2ACI/OTCT-ND
U4: ESD7002WTT1G; SOT-323_SC-70
U5: GD25Q16CEIGR; DFN-8-1EP_3x2mm_P0.5mm_EP1.3x1.5mm
Y1: 24Mhz; Crystal_SMD_2016-4Pin_2.0x1.6mm; MPN XRCGB24M000F0L00R0; Digikey 490-5575-1-ND

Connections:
+BATT: C11.1, D2.2 (A), J2.1 (+), J6.1, U3.3 (VBAT)
/BUTTON: C1.1, R3.2, U1.40 (PB4), U1.44 (BOOT0)
/FLASH_CSEL: U1.25 (PB12), U5.1 (CS/IO1)
/FLASH_MISO: U1.27 (PB14), U5.2 (SO)
/FLASH_MOSI: U1.28 (PB15), U5.5 (SI/IO0)
/FLASH_SCK: U1.26 (PB13), U5.6 (SCK)
/LED1: Q1.1 (G), R4.1, U1.10 (PA0)
/LED2: Q2.1 (G), R5.1, U1.11 (PA1)
/LED3: Q3.1 (G), R9.1, U1.12 (PA2)
/LED4: Q4.1 (G), R13.1, U1.13 (PA3)
/PA4: J3.5, U1.14 (PA4)
/PA5: J3.4, U1.15 (PA5)
/PA6: J3.3, U1.16 (PA6)
/PA7: J3.2, U1.17 (PA7)
/PA8: J3.1, U1.29 (PA8)
/PA9: J7.12, U1.30 (PA9)
/PA10: J7.11, U1.31 (PA10)
/PA13: J7.10, U1.34 (PA13)
/PA14: J7.9, U1.37 (PA14)
/PB5: J7.8, U1.41 (PB5)
/PB6: J7.7, U1.42 (PB6)
/PB7: J7.6, U1.43 (PB7)
/RESET: J7.5, U1.7 (NRST)
/RGB_CKI: D9.5 (CKI), U1.18 (PB0)
/RGB_SDI: D9.4 (SDI), U1.45 (PB8)
/USB_D+: J4.3 (D+), U1.33 (PA12), U4.1
/USB_D-: J4.2 (D-), U1.32 (PA11), U4.2
/VIN: C6.1, J7.3, JP1.1, SW2.2 (B), U2.3 (VIN)
/VUSB: C9.1, C13.2, D1.2 (A), D6.2 (A), J4.1 (VBUS), J7.2, U3.4 (VDD)
GND: C1.2, C2.2, C3.2, C4.2, C5.2, C6.2, C7.2, C8.2, C9.2, C10.2, C11.2, C12.2, C13.1, C14.2, C16.2, D3.1 (K), D9.6 (GND), J2.2 (-), J4.5 (GND), J4.6 (Shield), J7.1, Q1.2 (S), Q2.2 (S), Q3.2 (S), Q4.2 (S), R2.2, R4.2, R5.2, R6.2, R9.2, R13.2, U1.8 (VSSA), U1.20 (PB2), U1.23 (VSS), U1.35 (VSS), U1.47 (VSS), U1.49 (VSS), U2.1 (GND), U3.2 (VSS), U4.3 (GND), U5.4 (GND), Y1.2
unnamed: C8.1, U1.5 (PH0), Y1.1
unnamed: C10.1, U1.6 (PH1), Y1.3
unnamed: C14.1, U1.22 (VCAP_1)
unnamed: D1.1 (K), D2.1 (K), SW2.1 (A)
unnamed: D3.2 (A), R1.1
unnamed: D4.1 (K), R7.1
unnamed: D5.1 (K), R8.1
unnamed: D6.1 (K), R11.1
unnamed: D7.1 (K), R10.1
unnamed: D8.1 (K), R12.1
unnamed: J6.2, Q1.3 (D), R7.2
unnamed: J6.3, Q2.3 (D), R8.2
unnamed: J6.4, Q3.3 (D), R10.2
unnamed: J6.5, Q4.3 (D), R12.2
unnamed: JP1.2, R1.2
unnamed: R2.1, R3.1, SW1.2
unnamed: R6.1, U3.5 (PROG)
unnamed: R11.2, U3.1 (STAT)

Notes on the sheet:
Battery Charger
USB Connector
LEDs
3.3v Power
Power Indicator
RGB Status LED
Flash Memory
Debounced Button

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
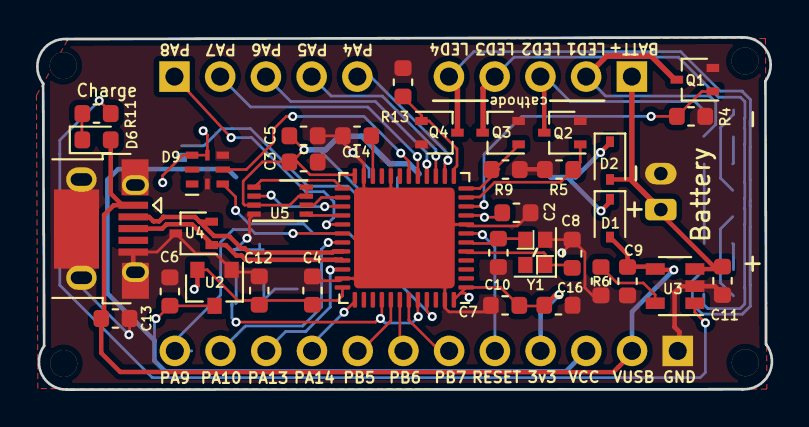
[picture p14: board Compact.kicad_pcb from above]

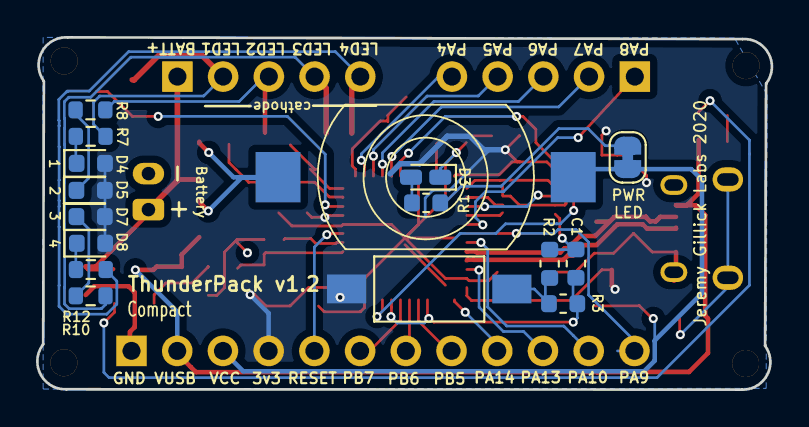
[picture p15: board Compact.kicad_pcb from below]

Board: 2 copper layers, 40.8 x 19.6 mm, 55 parts (16 on the bottom side), 49 nets.

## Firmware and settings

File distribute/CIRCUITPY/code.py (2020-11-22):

import time
import digitalio
from board import *

# Pin list
leds = [
    digitalio.DigitalInOut(LED1),
    digitalio.DigitalInOut(LED2),
    digitalio.DigitalInOut(LED3),
    digitalio.DigitalInOut(LED4),
]
btn = digitalio.DigitalInOut(BUTTON)
btn.direction = digitalio.Direction.INPUT

# Set all LEDs to output
for l in leds:
    l.direction = digitalio.Direction.OUTPUT

# Loop through LEDs
i = 0
num_leds = len(leds)
while True:
    leds[i].value = not leds[i].value

    # Faster when button pressed
    if btn.value:
        time.sleep(.05)
    else:
        time.sleep(.125)

    # Increment
    i += 1
    i = i % num_leds # wrap around back to 0 when we get to the end

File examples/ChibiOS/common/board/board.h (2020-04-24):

/*
    ChibiOS - Copyright (C) 2006..2018 Giovanni Di Sirio

    Licensed under the Apache License, Version 2.0 (the "License");
    you may not use this file except in compliance with the License.
    You may obtain a copy of the License at

        http://www.apache.org/licenses/LICENSE-2.0

    Unless required by applicable law or agreed to in writing, software
    distributed under the License is distributed on an "AS IS" BASIS,
    WITHOUT WARRANTIES OR CONDITIONS OF ANY KIND, either express or implied.
    See the License for the specific language governing permissions and
    limitations under the License.
*/

/*
 * This file has been automatically generated using ChibiStudio board
 * generator plugin. Do not edit manually.
 */

#ifndef BOARD_H
#define BOARD_H

/*===========================================================================*/
/* Driver constants.                                                         */
/*===========================================================================*/

/*
 * Setup for STMicroelectronics STM32 Nucleo144-F412ZG board.
 */

/*
 * Board identifier.
 */
#define BOARD_THUNDERPACK
#define BOARD_NAME                  "ThunderPack-STM32F411CE"

/**
 * No vbus line
 */
#define BOARD_OTG_NOVBUSSENS

/*
 * Board oscillators-related settings.
 * NOTE: LSE not fitted.
 */
#if !defined(STM32_LSECLK)
#define STM32_LSECLK                0U
#endif

#if !defined(STM32_HSECLK)
#define STM32_HSECLK                24000000U
#endif

// #define STM32_HSE_BYPASS

/*
 * Board voltages.
 * Required for performance limits calculation.
 */
#define STM32_VDD                   300U

/*
 * MCU type as defined in the ST header.
 */
#ifndef STM32F411xE
#define STM32F411xE
#endif

/*
 * IO pins assignments.
 */
#define GPIOA_PIN0                  0U
#define GPIOA_LED1                  0U
#define GPIOA_PIN1                  1U
#define GPIOA_LED2                  1U
#define GPIOA_PIN2                  2U
#define GPIOA_LED3                  2U
#define GPIOA_PIN3                  3U
#define GPIOA_LED4                  4U
#define GPIOA_PIN4                  4U
#define GPIOA_PIN5                  5U
#define GPIOA_PIN6                  6U
#define GPIOA_SPI1_MISO             6U
#define GPIOA_PIN7                  7U
#define GPIOA_SPI1_MOSI             7U
#define GPIOA_PIN8                  8U
#define GPIOA_USB_SOF               8U
#define GPIOA_PIN9                  9U
#define GPIOA_USB_VBUS              9U
#define GPIOA_PIN10                 10U
#define GPIOA_USB_ID                10U
#define GPIOA_PIN11                 11U
#define GPIOA_USB_DM                11U
#define GPIOA_PIN12                 12U
#define GPIOA_USB_DP                12U
#define GPIOA_PIN13                 13U
#define GPIOA_SWDIO                 13U
#define GPIOA_PIN14                 14U
#define GPIOA_SWCLK                 14U
#define GPIOA_PIN15                 15U
#define GPIOA_I2S3_WS               15U

#define GPIOB_PIN0                  0U
#define GPIOB_PIN1                  1U
#define GPIOB_PIN2                  2U
#define GPIOB_PIN3                  3U
#define GPIOB_PIN4                  4U
#define GPIOB_BUTTON                4U
#define GPIOB_PIN5                  5U
#define GPIOB_I2S3_SD               5U
#define GPIOB_PIN6                  6U
#define GPIOB_QUADSPI_BK1_NCS       6U
#define GPIOB_PIN7                  7U
#define GPIOB_PIN8                  8U
#define GPIOB_I2C1_SCL              8U
#define GPIOB_PIN9                  9U
#define GPIOB_I2C1_SDA              9U
#define GPIOB_PIN10                 10U
#define GPIOB_PIN11                 11U
#define GPIOB_PIN12                 12U
#define GPIOB_I2S2_WS               12U
#define GPIOB_PIN13                 13U
#define GPIOB_I2S2_CK               13U
#define GPIOB_PIN14                 14U
#define GPIOB_I2S2_SD               15U

#define LED_PAD0                    0u
#define LED_PAD1                    1u
#define LED_PAD2                    2u
#define LED_PAD3                    3u

/*
 * IO lines assignments.
 */
#define LINE_TIM2_CH1               PAL_LINE(GPIOA, 0U)
#define LINE_TIM2_CH2               PAL_LINE(GPIOA, 1U)
#define LINE_TIM2_CH3               PAL_LINE(GPIOA, 2U)
#define LINE_TIM2_CH4               PAL_LINE(GPIOA, 3U)
#define LINE_SPI3_NSS               PAL_LINE(GPIOA, 4U)
#define LINE_SPI1_SCK               PAL_LINE(GPIOA, 5U)
#define LINE_SPI1_MISO              PAL_LINE(GPIOA, 6U)
#define LINE_SPI1_MOSI              PAL_LINE(GPIOA, 7U)
#define LINE_USB_SOF                PAL_LINE(GPIOA, 8U)
#define LINE_USB_VBUS               PAL_LINE(GPIOA, 9U)
#define LINE_USB_ID                 PAL_LINE(GPIOA, 10U)
#define LINE_USB_DM                 PAL_LINE(GPIOA, 11U)
#define LINE_USB_DP                 PAL_LINE(GPIOA, 12U)
#define LINE_SWDIO                  PAL_LINE(GPIOA, 13U)
#define LINE_SWCLK                  PAL_LINE(GPIOA, 14U)
#define LINE_I2S3_WS                PAL_LINE(GPIOA, 15U)
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

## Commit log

2018-09-03 Add hardware
    [LEDRibbonController-2018-09-02-17-51-32.sch, LEDRibbonController.kicad_pcb, LEDRibbonController.sch]
2018-09-04 Upgrade to kicad 5
    [LEDRibbonController-2018-09-02-23-24-38.sch, LEDRibbonController.kicad_pcb, LEDRibbonController.sch]
2018-09-13 Populate PCB with ALL THE NEW THINGS
    [LEDRibbonController.kicad_pcb, LEDRibbonController.sch]
2018-09-13 Remove VCC
    [LEDRibbonController.kicad_pcb, LEDRibbonController.sch]
2018-09-14 Finish routing
    [LEDRibbonController.kicad_pcb, LEDRibbonController.sch]
2018-09-14 Adjust routing
    [LEDRibbonController.kicad_pcb]
2018-09-18 Move hardware files
    [LEDRibbonController-2018-09-02-23-24-38.sch, LEDRibbonController.kicad_pcb, LEDRibbonController.sch]
2018-09-18 Rename hardware files
    [LitFist18650.kicad_pcb, LitFist18650.sch]
2018-09-18 Fix battery number from 8650 to 18650
    [LEDRibbonController-2018-09-02-23-24-38.sch, LitFist18650.kicad_pcb, LitFist18650.sch]
2018-09-18 misc save
    [LitFist18650.kicad_pcb]
2018-10-22 Fix Attiny footprint. Add debounce circuit.
    [LitFist18650.kicad_pcb, LitFist18650.sch]
2018-10-28 Move Attiny version of hardware
    [LitFist18650.kicad_pcb, LitFist18650.sch]
2018-10-29 minor save
    [LitFist18650.sch]
2018-10-29 Add STM32
    [STM32L0xx_18650.kicad_pcb, STM32L0xx_18650.sch]
2018-10-31 Basic schematic
    [STM32L0xx_18650.kicad_pcb]
2018-10-31 Update LED circuit
    [STM32L0xx_18650.sch]
2019-05-07 PCB for fab
    [STM32L0xx_18650.kicad_pcb]
2019-09-06 Update hardware
    [STM32L0xx_18650.kicad_pcb, STM32L0xx_18650.sch]
2019-09-06 Fix ChibiOS name casing.
    [LEDController.cpp, board.c, board.h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]
2019-09-07 Move kicad files.
    [STM32L0xx_18650.kicad_pcb, STM32L0xx_18650.sch]
2019-09-07 Remove attiny hardware.
    [LitFist18650.kicad_pcb, LitFist18650.sch]
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2019-09-09 Rename LitFist to Thunder Pack
    [STM32L0xx_18650.kicad_pcb, STM32L0xx_18650.sch]
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2019-09-10 Add a full 10-pin JTAG connector.
    [STM32L0xx_18650.kicad_pcb, STM32L0xx_18650.sch]
2019-09-11 Change to 32 pin package.
    [STM32L0xx_18650.kicad_pcb, STM32L0xx_18650.sch]
2019-09-11 Add top labels and cleanup.
    [STM32L0xx_18650.kicad_pcb, STM32L0xx_18650.sch]
2019-09-11 Use standard parts/symbols
    [STM32L0xx_18650.kicad_pcb, STM32L0xx_18650.sch]
2019-09-12 Update charger IC (MCP73833-AMI_UN)
    [STM32L0xx_18650.kicad_pcb, STM32L0xx_18650.sch]
2019-09-12 Add PWM fade example to libopencm3. Fix make files.
    [main.c]
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2019-09-17 Make PCB labels bigger. Export gerbers.
    [STM32L0xx_18650-B_Cu.gbr, STM32L0xx_18650-B_Mask.gbr, STM32L0xx_18650-B_Paste.gbr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]
2019-09-18 Update trace
    [STM32L0xx_18650.kicad_pcb]
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2019-10-14 Convert 4 layer -> 2 layer PCB (#2)
    [STM32L0xx_18650-B_Cu.gbl, STM32L0xx_18650-B_Cu.gbr, STM32L0xx_18650-B_Mask.gbr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]
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2019-10-14 Fix USB pin line
2019-10-15 Hardware feedback.
    [STM32L0xx_18650-B_Cu.gbl, STM32L0xx_18650-B_Mask.gbs, STM32L0xx_18650-B_Paste.gbp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]
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2019-10-17 Change USB TVS.
    [STM32L0xx_18650.kicad_pcb, STM32L0xx_18650.sch]
2019-10-21 Fix arduino sketch name.
2019-10-21 Change battery changing controller
    [STM32L0xx_18650-B_Cu.gbl, STM32L0xx_18650-B_Mask.gbs, STM32L0xx_18650-B_Paste.gbp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]
2019-10-22 Add USART, I2C & SPI pins to silkscreen
    [STM32L0xx_18650-B_Cu.gbl, STM32L0xx_18650-B_Mask.gbs, STM32L0xx_18650-B_Paste.gbp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]
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2019-11-06 Change BATT+ to Vin
    [STM32L0xx_18650-B_Cu.gbl, STM32L0xx_18650-B_Mask.gbs, STM32L0xx_18650-B_Paste.gbp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]
2019-11-07 Add OSH logo
    [STM32L0xx_18650-B_Cu.gbl, STM32L0xx_18650-B_Mask.gbs, STM32L0xx_18650-B_Paste.gbp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]
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2019-11-07 Change `PWM` to `LEDs`
    [STM32L0xx_18650-B_Cu.gbl, STM32L0xx_18650-B_Mask.gbs, STM32L0xx_18650-B_Paste.gbp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]
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2019-11-18 Update gerbers for alpha version 1a4
    [STM32L0xx_18650-Edge_Cuts.gko, STM32L0xx_18650-Edge_Cuts.gm1]
2019-11-19 Update charge indicator LED
    [STM32L0xx_18650.sch]
2019-12-01 Fix issue where last two LEDs don't get data.
    [ws2812b.c]
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2020-01-18 Adjust space around battery terminals.
    [14500-B_Cu.gbl, 14500-B_Mask.gbs, 14500-B_Paste.gbp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]
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2020-01-18 Fix spacing around battery clips.
    [14500-B_Cu.gbl, 14500-B_Mask.gbs, 14500-B_Paste.gbp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]
2020-01-18 Update version number (1a2)
    [14500-B_Cu.gbl, 14500-B_Mask.gbs, 14500-B_Paste.gbp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]
2020-01-19 Add "Tiny" version with 10440 battery
    [10440-B_Cu.gbl, 10440-B_Mask.gbs, 10440-B_Paste.gbp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]
2020-01-25 Add "fp-info-cache" to git ignore and remove space in dir name.
    [10440-B_Cu.gbl, 10440-B_Mask.gbs, 10440-B_Paste.gbp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]
2020-01-30 Use STM32F412CGUx (Regular & Tiny)
    [10440.kicad_pcb, 10440.sch, 14500.kicad_pcb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]
2020-01-30 Finish updating Small board with STM32F4
    [10440.kicad_pcb, 14500.kicad_pcb, 14500.sch]
2020-01-30 Rename files to remove MCU name
    [18650.kicad_pcb, 18650.sch]
2020-02-01 Update BOM & gerbers
    [10440-B_Cu.gbl, 10440-B_Mask.gbs, 10440-B_Paste.gbp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]
2020-02-03 Update gerbers for pcbway
    [18650-B_Cu.gbl, 18650-B_Mask.gbs, 18650-B_Paste.gbp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]
2020-02-03 Update gerbers with origins
    [10440-B_Cu.gbl, 10440-B_Mask.gbs, 10440-B_Paste.gbp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]
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2020-02-18 Add extra ground pin.
    [18650.kicad_pcb, 18650.sch]
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2020-03-26 Update pins and arduino examples.
    [18650.kicad_pcb, 18650.sch]
2020-03-27 Fix dfu-util device targeting.
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2020-04-15 Fix addressable LEDs example in libopencm3
    [main.c, ws2812b.c, ws2812b_conf.h]
2020-04-15 Try to fix Addressable LEDs for Chibios (not working)
    [main.c, mcuconf.h, ws2812b.c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]
2020-04-15 Fix EEPROM example for Chibios.
    [board.h, main.c]
2020-04-15 Fix USBSerial example for Chibios.
    [board.h, halconf.h, main.c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]
2020-04-15 Fix threads example.
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2020-04-18 Fix Arduino addressable LEDs example.
    [AddressableLEDs.ino, WS2812b.cpp, WS2812b.h]
2020-11-22 ThunderPack v1.2 (#5)
    * Compact version (4cm x 1.9cm)
    * Onboard 16MB flash chip
    * Illuminated switch
    * RGB DotStar LED
    * New battery charger chip.
    [10440-B_Cu.gbl, 10440-B_Mask.gbs, 10440-B_Paste.gbp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]
2020-12-22 Add ESD. Update labeling
    [Compact-B_Cu.gbr, Compact-B_Mask.gbr, Compact-B_Paste.gbr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]
2021-01-27 Cleanup fills and labels.
    [Compact.kicad_pcb]
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2026-10-23 Fix pin number
